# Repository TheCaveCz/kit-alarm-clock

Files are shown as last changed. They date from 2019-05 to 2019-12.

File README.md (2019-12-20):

# Alarm clock / Budík

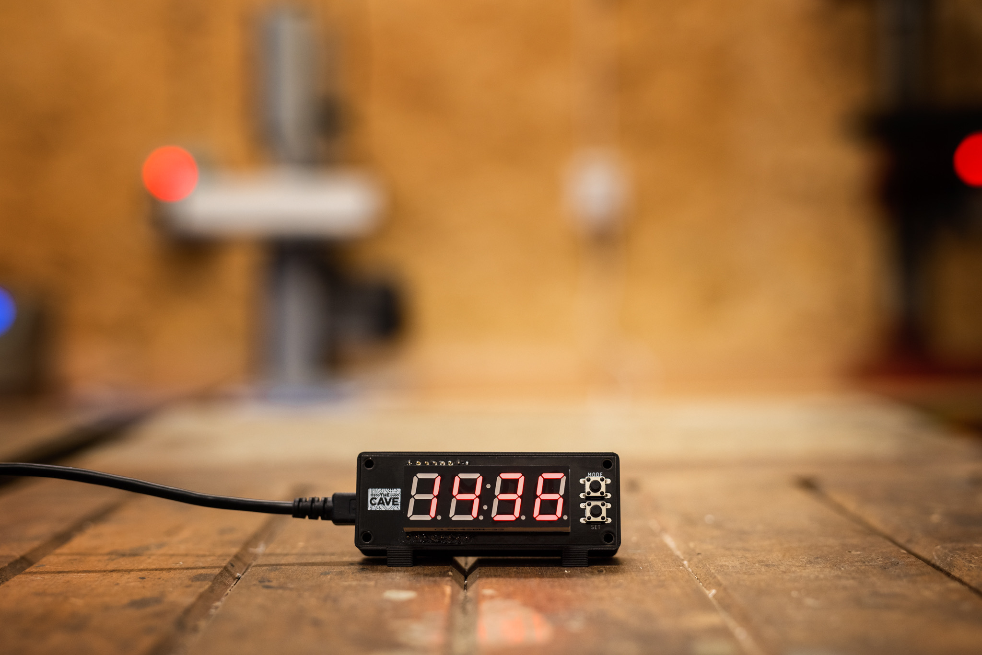
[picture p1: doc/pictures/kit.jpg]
Dice


## Česky

Stavebnice digitálních hodin s budíkem ovládaných přes WiFI.

* [Návod na stavbu](doc/manual-cz.md) ([PDF](doc/manual-cz.pdf))
* [Nastavení budíku a aplikace](doc/blynk-cz.md)
* [Nahrání nového firmware](doc/firmware-cz.md)

## English

Coming soon...

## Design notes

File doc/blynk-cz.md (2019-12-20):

# Nastavení

## Aplikace Blynk

* Stáhněte a nainstalujte si aplikaci Blynk (https://blynk.io/en/getting-started)
* Vytvořte si v aplikaci Blynk nový účet/přihlašte se pokud už účet máte
* Vytvořte v aplikaci nový projekt (New project), device je `Wemos D1 mini`, connection type je `WiFi`
* Blynk odešle na mail zadaný při registraci **Auth token**, ten si zkopírujte nebo opište, budeme jej potřebovat v dalším kroku

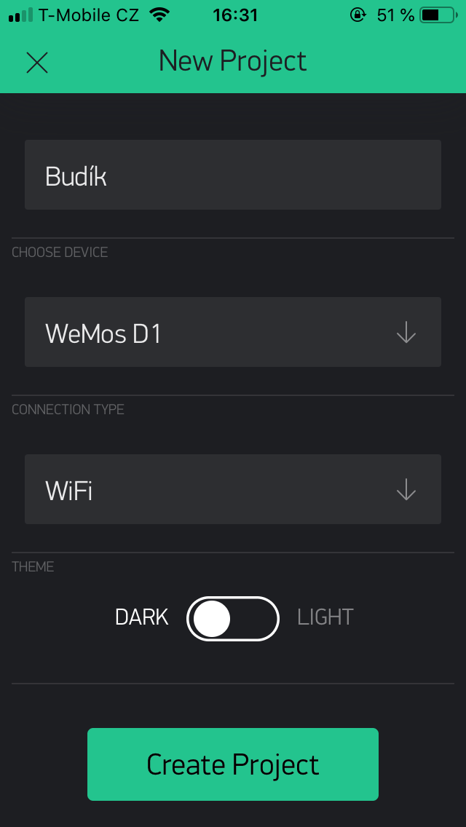
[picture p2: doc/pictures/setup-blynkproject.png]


## Připojení hodin k WiFi

Na displeji hodin musí svítit **AP** a je potřeba mít Blynk **Auth token**. Připojte se na WiFi `alarm-clock-xxxxxx` (xxxxxx je číslo hodin, může se měnit).

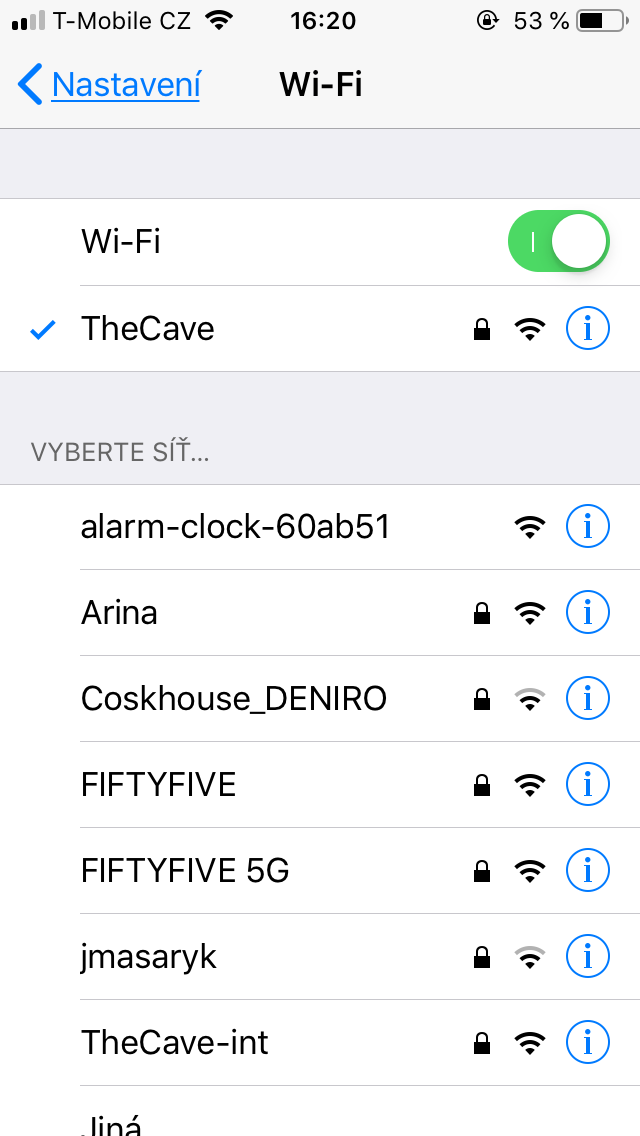
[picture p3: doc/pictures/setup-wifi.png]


Objeví se nastavovací obrazovka (to může chvíli trvat, na některých Android telefonech je potřeba ji ručně otevřít). Pokud se obrazovka neobjeví, zadejte do prohlížeče adresu http://192.168.4.1/, poté zvolte možnost Configure WiFi a počkejte, dokud se neobjeví výběr WiFi sítí.

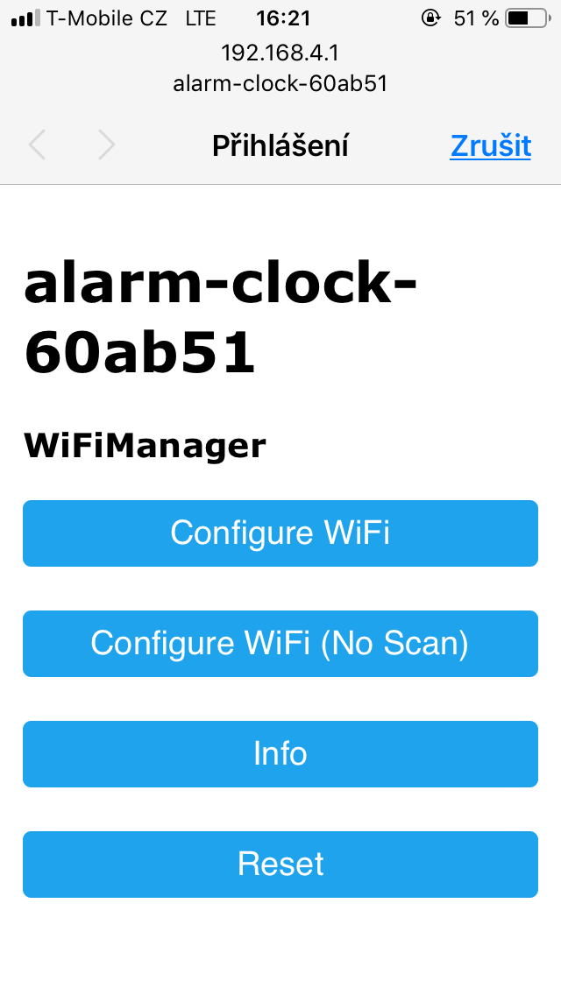
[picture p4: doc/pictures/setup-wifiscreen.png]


Vyberte vaši WiFi síť a do prostředního políčka napište její heslo. Do posledního políčka vložte Auth token a stiskněte tlačítko `Save`

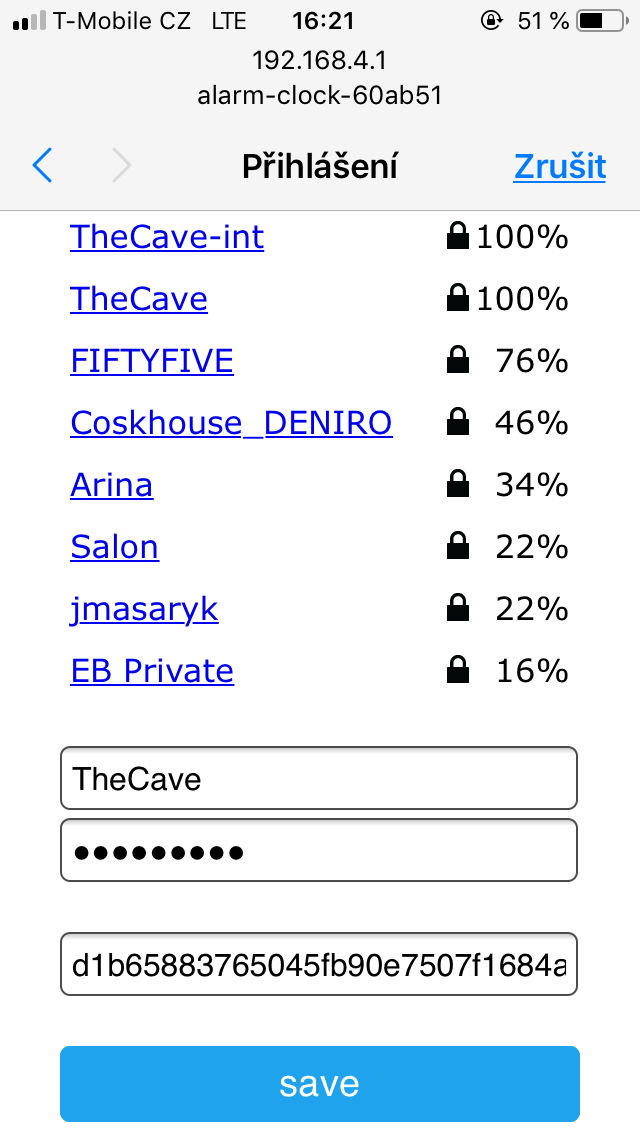
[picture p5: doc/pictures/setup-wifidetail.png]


Po připojení k WiFi na hodinách svítí nuly.

## Nastavení projektu Blynk

Otevřete aplikaci Blynk a zvolte projekt budíku. Obrazovka by měla vypadat podobně.

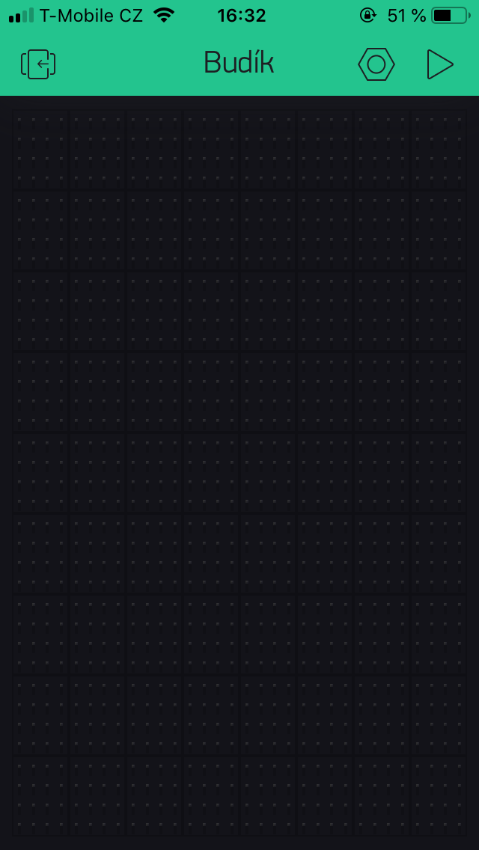
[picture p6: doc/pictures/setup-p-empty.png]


V aplikaci Blynk otevřete projekt a přidejte první kompnentu (na Androidu klepnutím na plus v kolečku, na iOS swipem doleva).

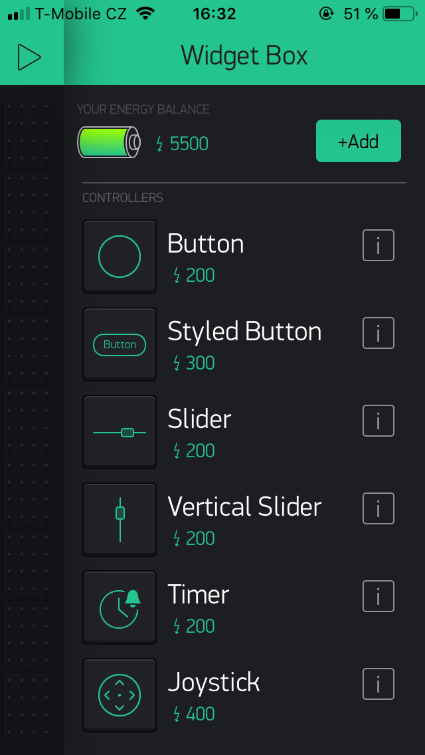
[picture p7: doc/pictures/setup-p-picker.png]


První komponenta, kterou přidáme je **Real-time Clock**. Klepněte na ikonu Play v pravém horním rohu a restartujte hodiny (stiskem tlačítka reset nebo odpojením a připojením kabelu). Pokud vše proběhlo v pořádku, na displeji je aktuální čas.

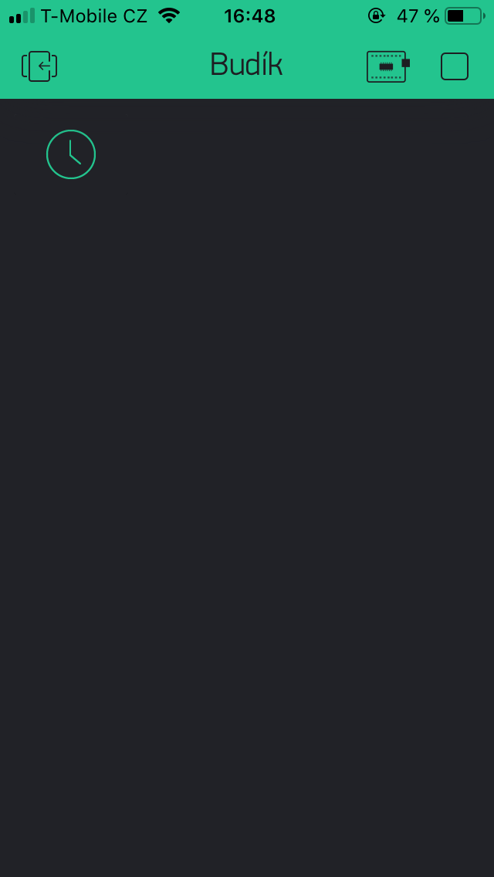
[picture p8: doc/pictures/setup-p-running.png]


Klepněte na ikonu Stop a přidejte další komponenty: **Time Input**, .**Button** a **Notification**. Klepnutím na každou komponentu Time Input otevřete její nastavení a nastavte ji podle následujícího obrázku:

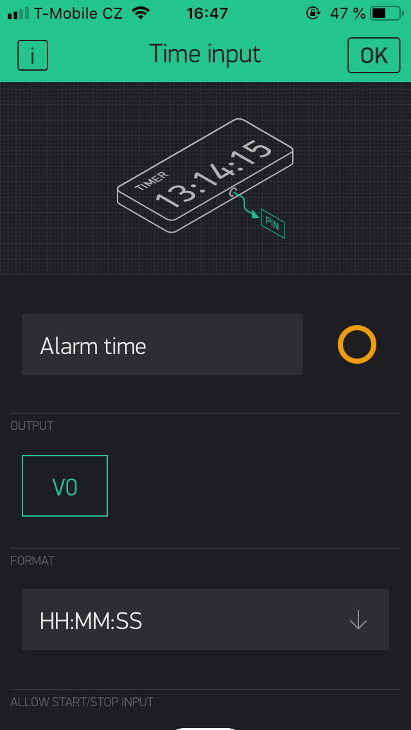
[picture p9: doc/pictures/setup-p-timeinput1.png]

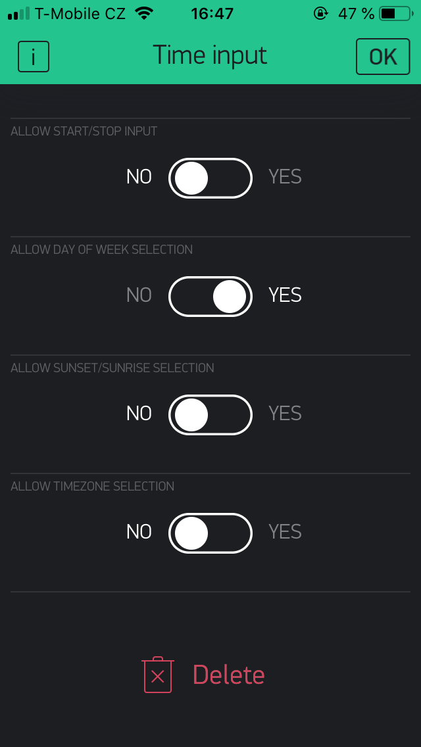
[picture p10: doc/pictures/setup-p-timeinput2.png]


Další komponenta, kterou nastavíme je Button:

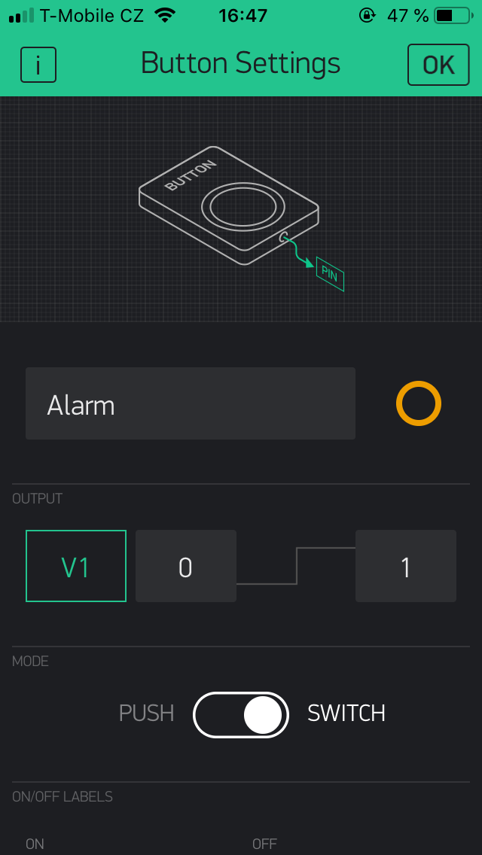
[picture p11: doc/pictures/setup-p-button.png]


Další komponenta je Notification:

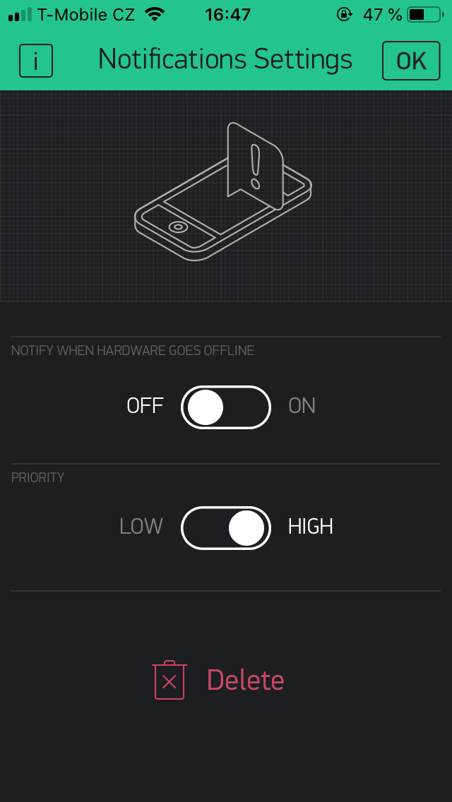
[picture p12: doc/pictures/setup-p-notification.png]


A je to, základní nastavení je hotovo, nyní stiskněte ikonu Play a projekt by měl vypadat nějak takto:

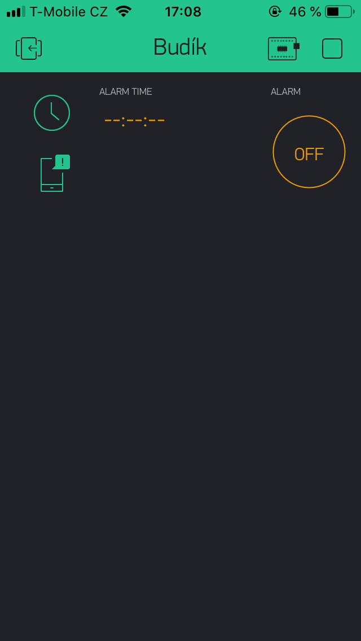
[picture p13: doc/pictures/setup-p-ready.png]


Klepnutím na Alarm time můžete nastavit čas a dny alarmu.

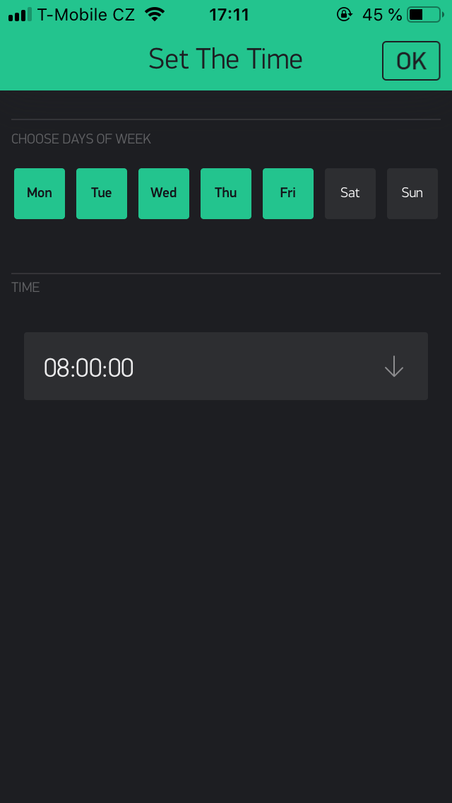
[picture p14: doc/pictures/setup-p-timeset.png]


Tímto jste úspěšně nastavili vše potřebné pro provoz budíku, gratulujeme!

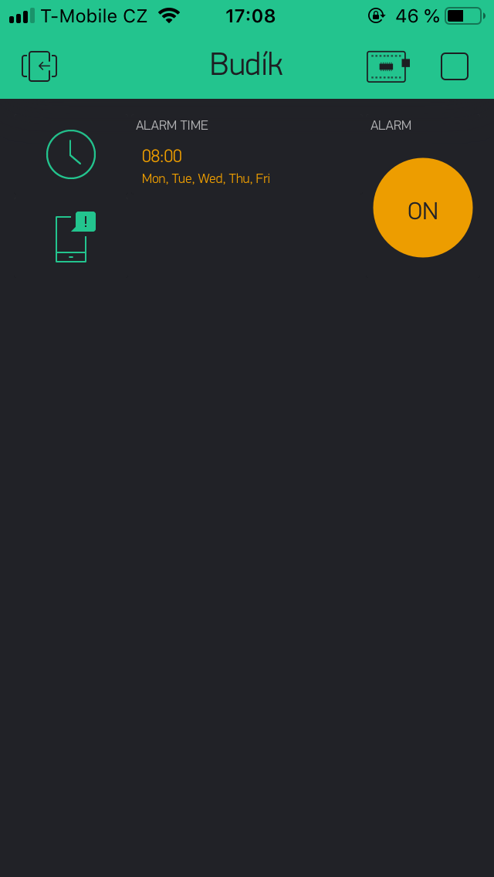
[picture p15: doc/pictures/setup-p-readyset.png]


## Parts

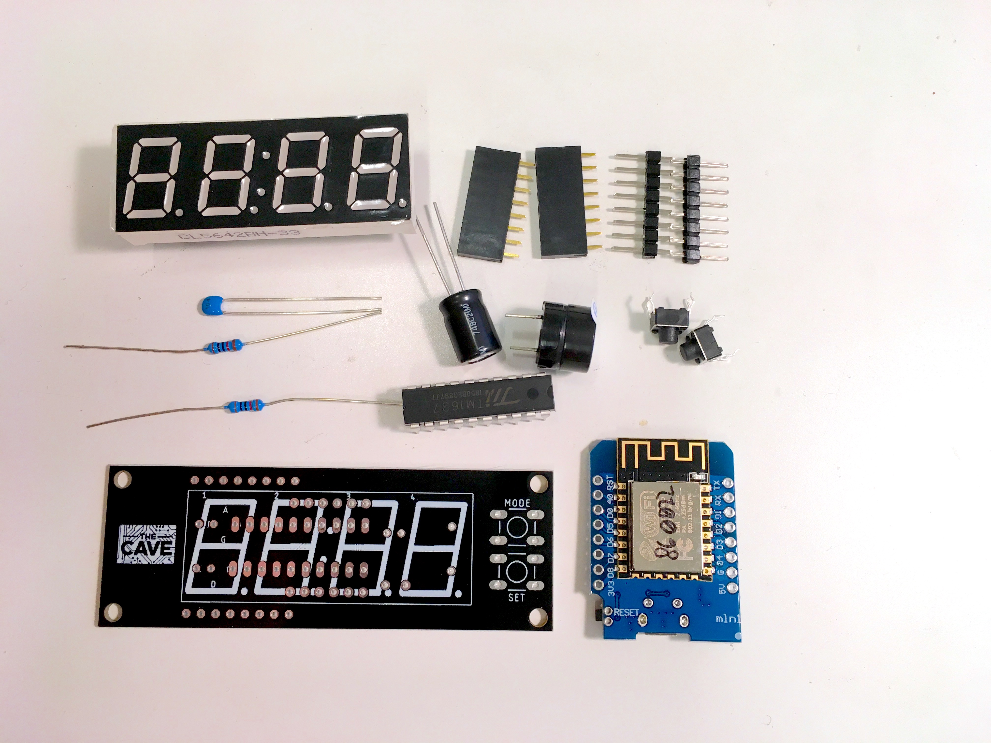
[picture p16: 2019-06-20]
doc/pictures/parts.jpg

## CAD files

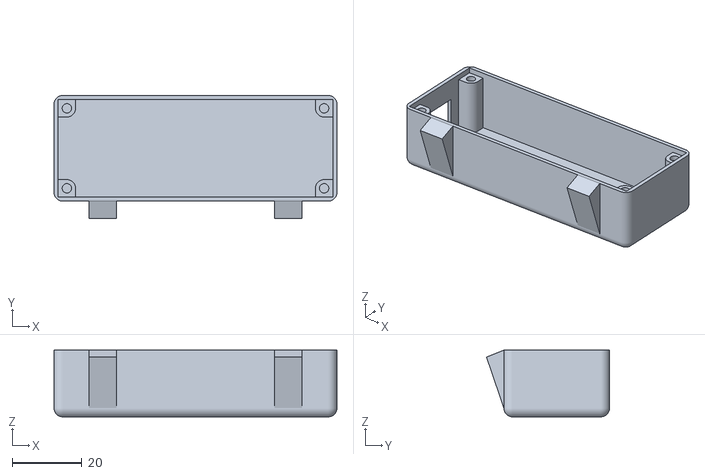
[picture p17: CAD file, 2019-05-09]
stl/box-alarm-clock.stl
81.4 x 35.4 x 19.2

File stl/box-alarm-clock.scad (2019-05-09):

/*
 * Alarm clock kit box
 * 
 * The Cave, 2019
 * https://thecave.cz
 * 
 * Licensed under MIT License (see LICENSE file for details)
 *
 */
$pcbW = 79;
$pcbH = 28;
$pcbThickness = 1.6;
$innerZ = 18;

$usbW = 12;
$usbH = 10;
$usbOffsetZ = 6.5;
$usbOffsetY = 0.5;

$wall = 1.2;
$radius = 5.08;
$fn=100;

$standZ = $innerZ-$pcbThickness;
$standDia = 5;

difference() {
    translate([$radius/2,$radius/2,$radius/2]) minkowski() {
        cube([$pcbW+$wall*2-$radius,$pcbH+$wall*2-$radius,$innerZ+$radius*2+$wall]);
        sphere(d=$radius);
    }
    
    translate([$wall,$wall,$wall]) cube([$pcbW,$pcbH,$innerZ+1]);
    translate([-1,-1,$wall+$innerZ]) cube([$pcbW+$wall*2+10,$pcbH+$wall*2+10,30]);
    
    translate([-1, (($wall*2+$pcbH-$usbW)/2)-$usbOffsetY, $wall+$innerZ-$usbOffsetZ-$usbH]) #cube([$wall*4,$usbW,$usbH]);
}

translate([$wall,$wall,$wall]) {
    difference() {
        union() {
            translate([$standDia/2,$standDia/2,0]) cylinder(d=$standDia,h=$standZ);
            cube([$standDia,$standDia/2,$standZ]);
            cube([$standDia/2,$standDia,$standZ]);
            
            translate([$pcbW-$standDia/2,$standDia/2,0]) cylinder(d=$standDia,h=$standZ);
            translate([$pcbW-$standDia,0,0]) cube([$standDia,$standDia/2,$standZ]);
            translate([$pcbW-$standDia/2,0,0]) cube([$standDia/2,$standDia,$standZ]);
            
            translate([$standDia/2,$pcbH-$standDia/2,0]) cylinder(d=$standDia,h=$standZ);
            translate([0,$pcbH-$standDia/2,0]) cube([$standDia,$standDia/2,$standZ]);
            translate([0,$pcbH-$standDia,0]) cube([$standDia/2,$standDia,$standZ]);
            
            translate([$pcbW-$standDia/2,$pcbH-$standDia/2,0]) cylinder(d=$standDia,h=$standZ);
            translate([$pcbW-$standDia,$pcbH-$standDia/2,0]) cube([$standDia,$standDia/2,$standZ]);
            translate([$pcbW-$standDia/2,$pcbH-$standDia,0]) cube([$standDia/2,$standDia,$standZ]);
        }
        
        translate([$standDia/2,$standDia/2,0]) #cylinder(d=2.7,h=$standZ+5);
        translate([$pcbW-$standDia/2,$standDia/2,0]) #cylinder(d=2.7,h=$standZ+5);
        translate([$standDia/2,$pcbH-$standDia/2,0]) #cylinder(d=2.7,h=$standZ+5);
        translate([$pcbW-$standDia/2,$pcbH-$standDia/2,0]) #cylinder(d=2.7,h=$standZ+5);
    }
}

$legOffset = -5;
$legWidth = 8;
module leg() { polyhedron(
    points=[[0,0,$radius/2],[0,0,$wall+$innerZ],[0,$legOffset,$wall+$innerZ-2],[$legWidth,0,$radius/2],[$legWidth,0,$wall+$innerZ],[$legWidth,$legOffset,$wall+$innerZ-2]],
    faces=[[0,1,2],[2,1,4,5],[5,4,3],[3,4,1,0],[3,0,2,5]],
    convexity=1
);
}

translate([10,0,0]) leg();
translate([$wall*2+$pcbW-$legWidth-10,0,0]) leg();

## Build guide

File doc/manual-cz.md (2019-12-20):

# Návod na stavbu

[Stáhnout PDF](manual-cz.pdf)

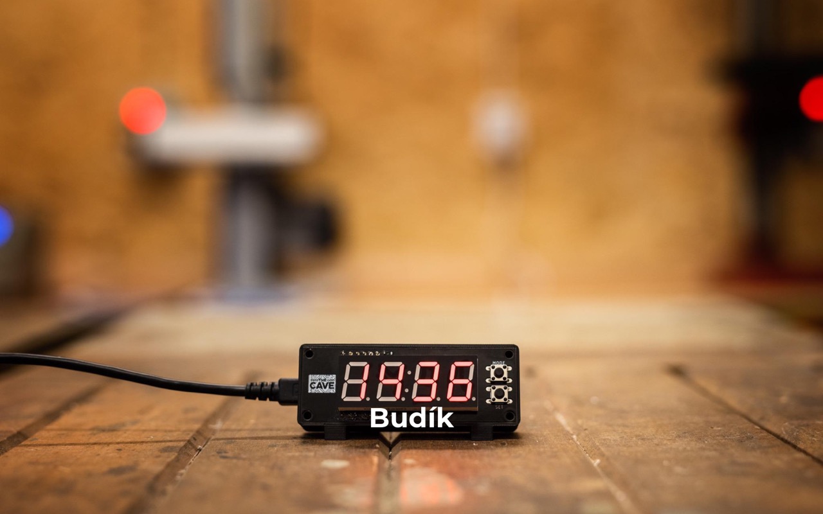
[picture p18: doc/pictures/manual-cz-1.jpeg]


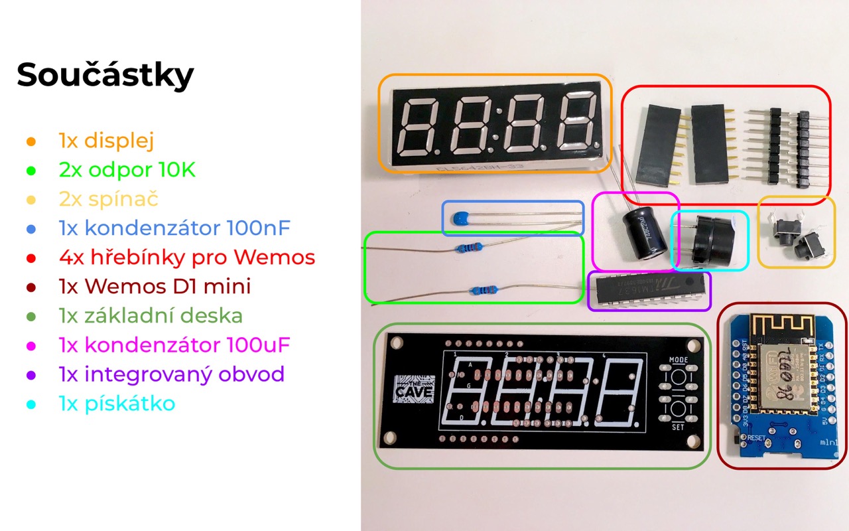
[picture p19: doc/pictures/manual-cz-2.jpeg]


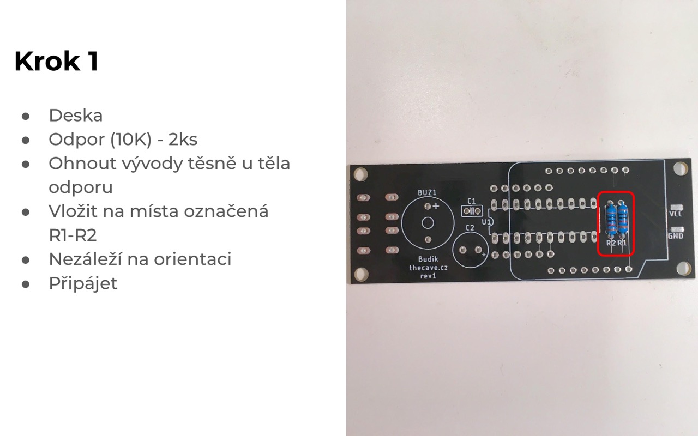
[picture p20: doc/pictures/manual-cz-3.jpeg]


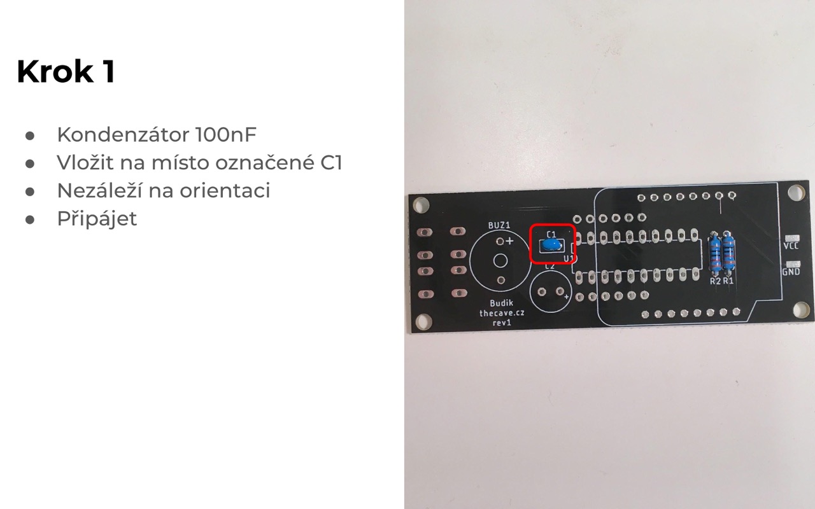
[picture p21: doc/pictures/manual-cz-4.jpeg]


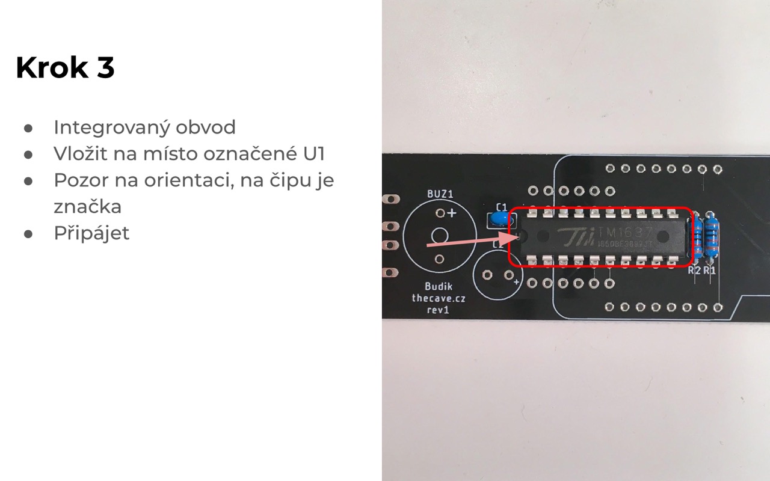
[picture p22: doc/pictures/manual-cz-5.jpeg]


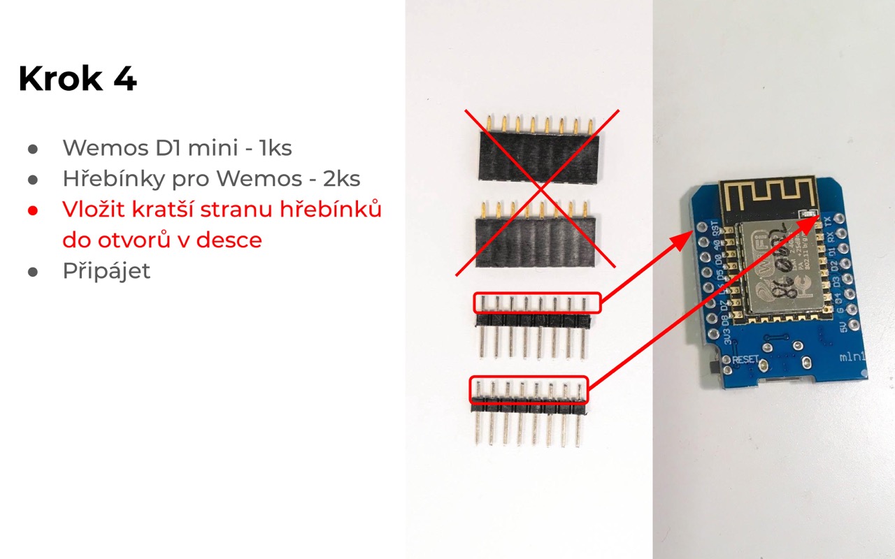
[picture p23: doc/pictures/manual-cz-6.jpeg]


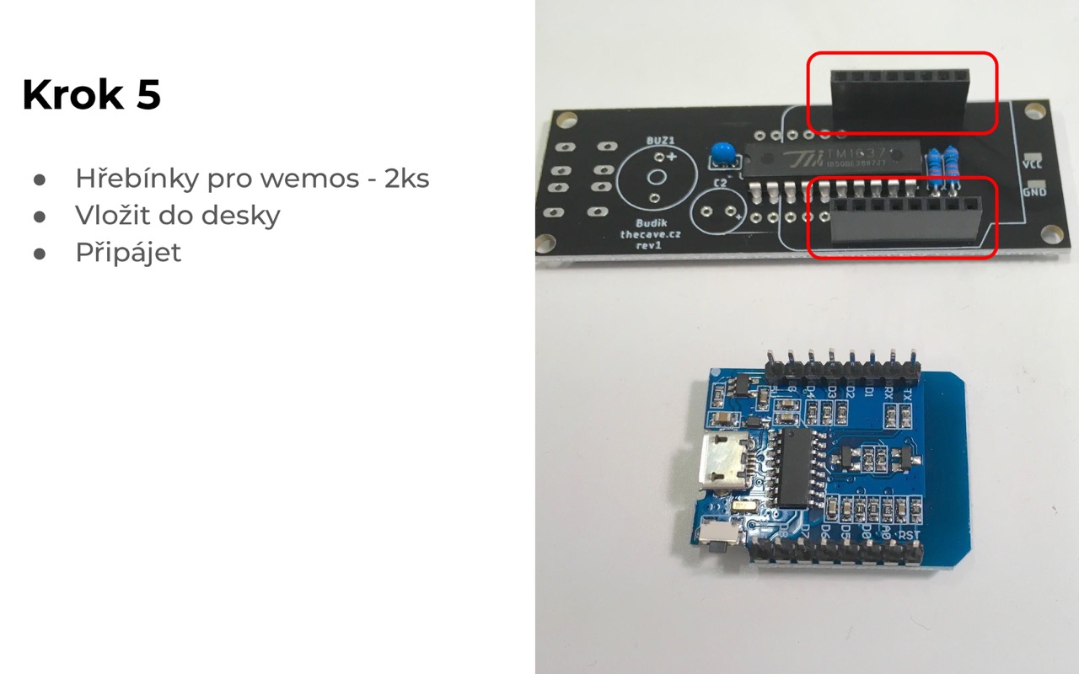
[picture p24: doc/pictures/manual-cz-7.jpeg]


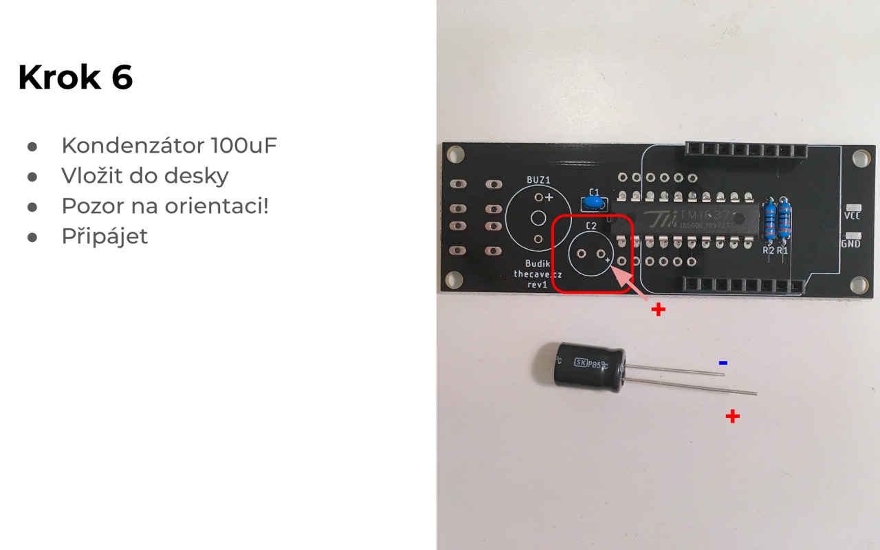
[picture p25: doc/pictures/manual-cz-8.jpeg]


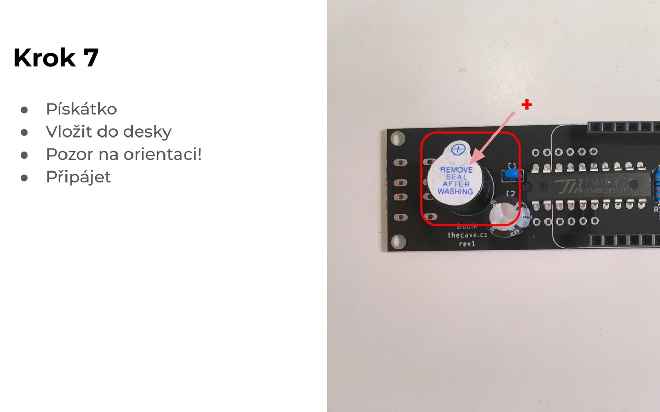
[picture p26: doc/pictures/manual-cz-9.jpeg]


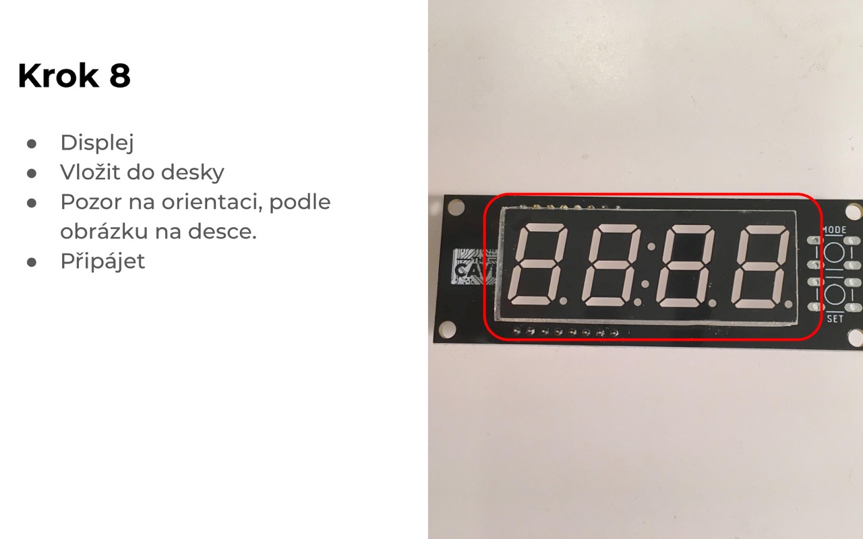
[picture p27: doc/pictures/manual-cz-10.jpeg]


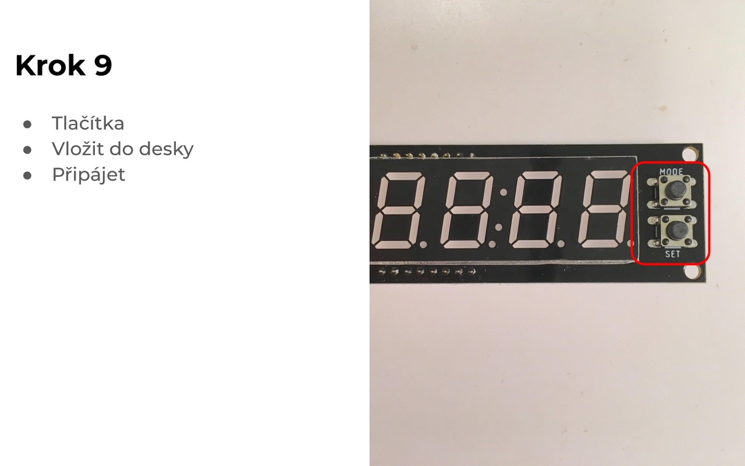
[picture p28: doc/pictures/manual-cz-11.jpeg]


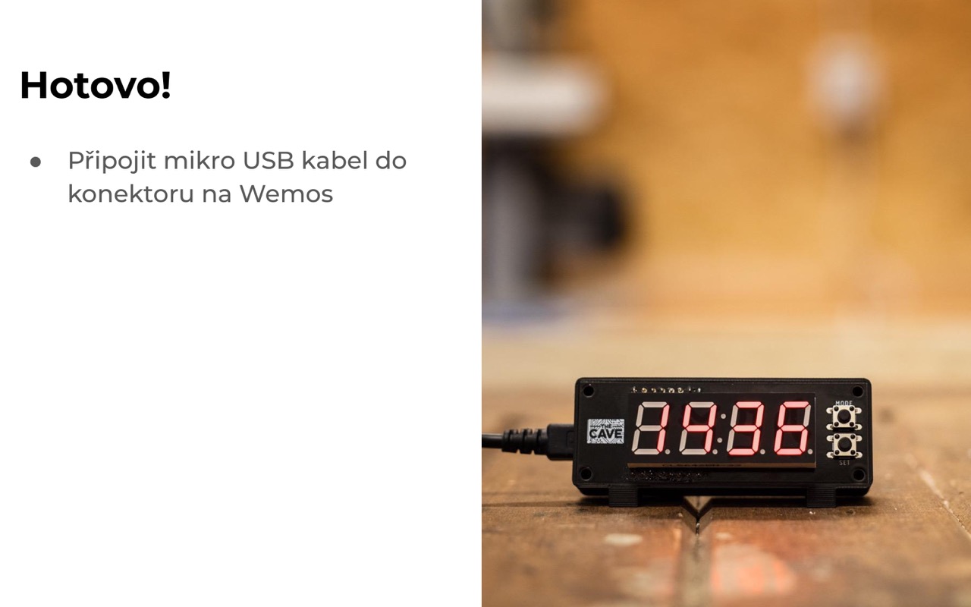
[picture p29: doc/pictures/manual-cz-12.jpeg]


[Nastavení budíku a aplikace](blynk-cz.md)

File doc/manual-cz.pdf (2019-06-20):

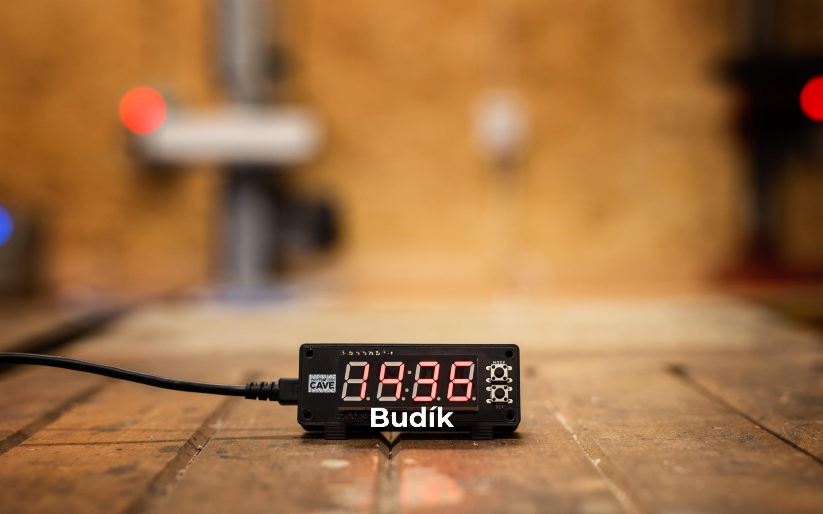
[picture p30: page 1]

## Budík

## Součástky

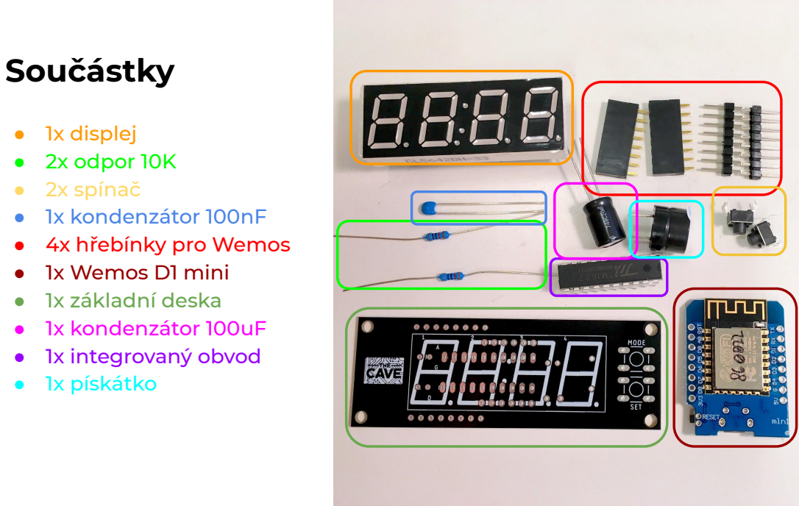
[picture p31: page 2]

● 1x displej
● 2x odpor 10K
● 2x spínač
● 1x kondenzátor 100nF
● 4x hřebínky pro Wemos
● 1x Wemos D1 mini
● 1x základní deska
● 1x kondenzátor 100uF
● 1x integrovaný obvod
● 1x pískátko

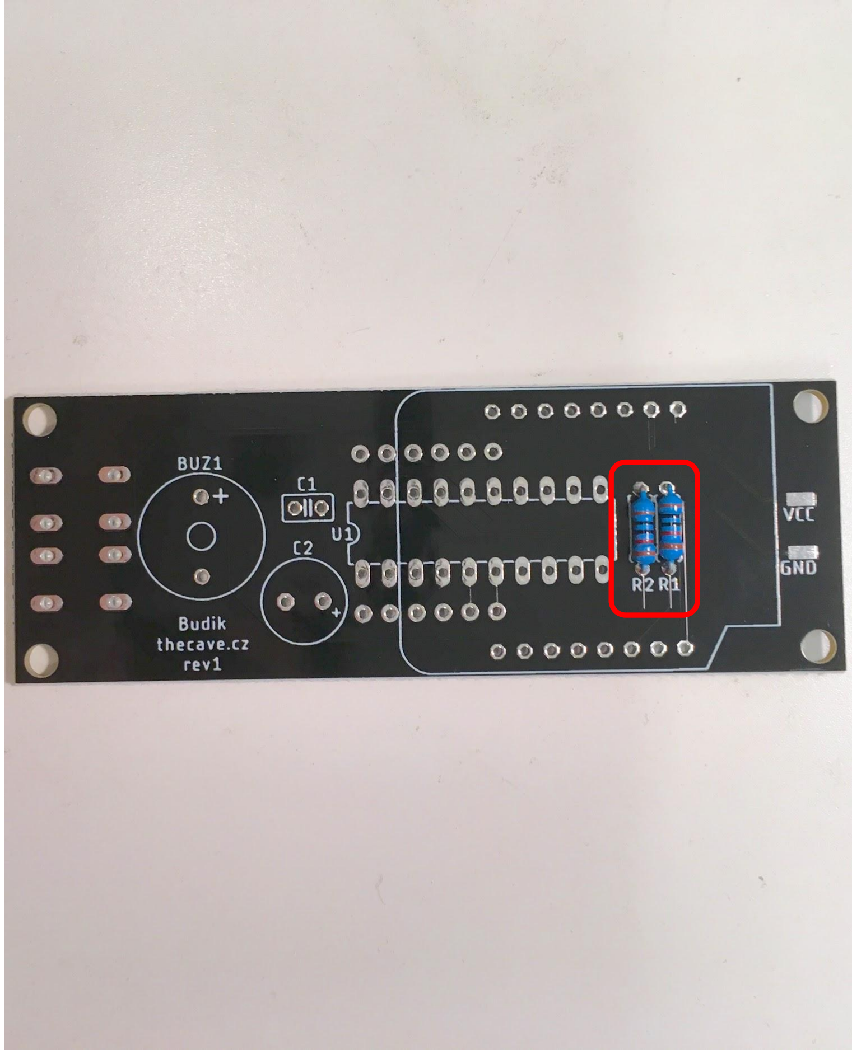
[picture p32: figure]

## Krok 1

- Deska
- Odpor (10K) - 2ks
- Ohnout vývody těsně u těla odporu
- Vložit na místa označená R1-R2
- Nezáleží na orientaci
- Připájet

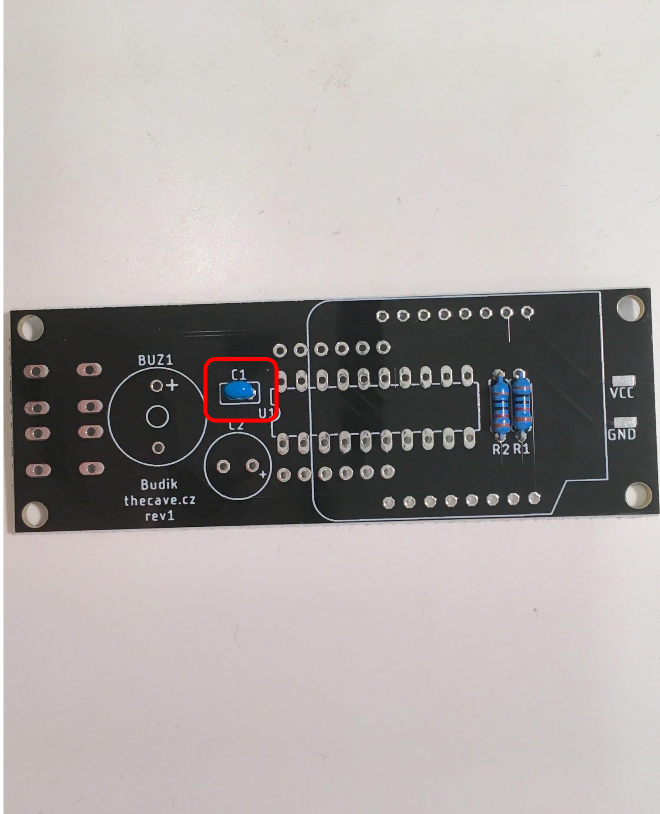
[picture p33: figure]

## Krok 1

- Kondenzátor 100nF
- Vložit na místo označené C1
- Nezáleží na orientaci
- Připájet

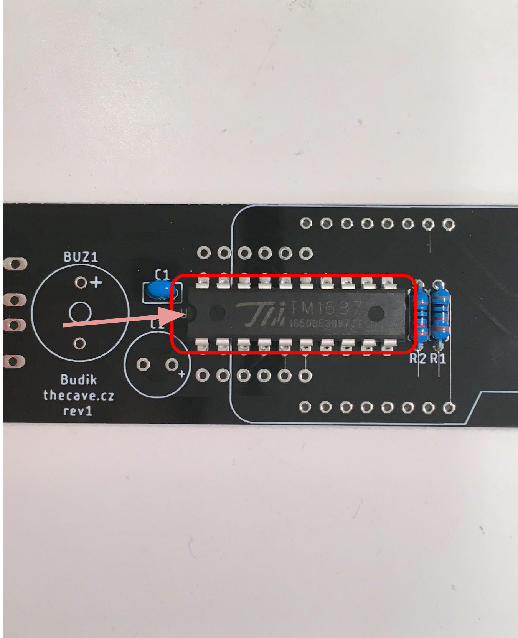
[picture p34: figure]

## Krok 3

- Integrovaný obvod
- Vložit na místo označené U1
- Pozor na orientaci, na čipu je značka
- Připájet

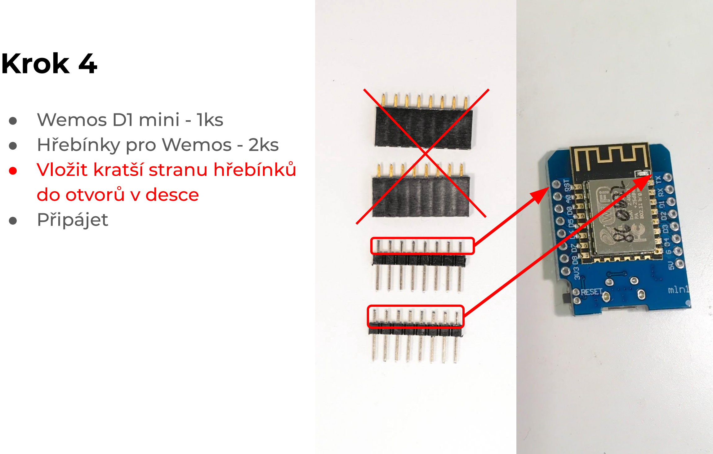
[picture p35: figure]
Krok 4; ● Wemos D1 mini - 1ks ● Hřebínky pro Wemos - 2ks ● Vložit kratší stranu hřebínků do otvorů v desce ● Připájet

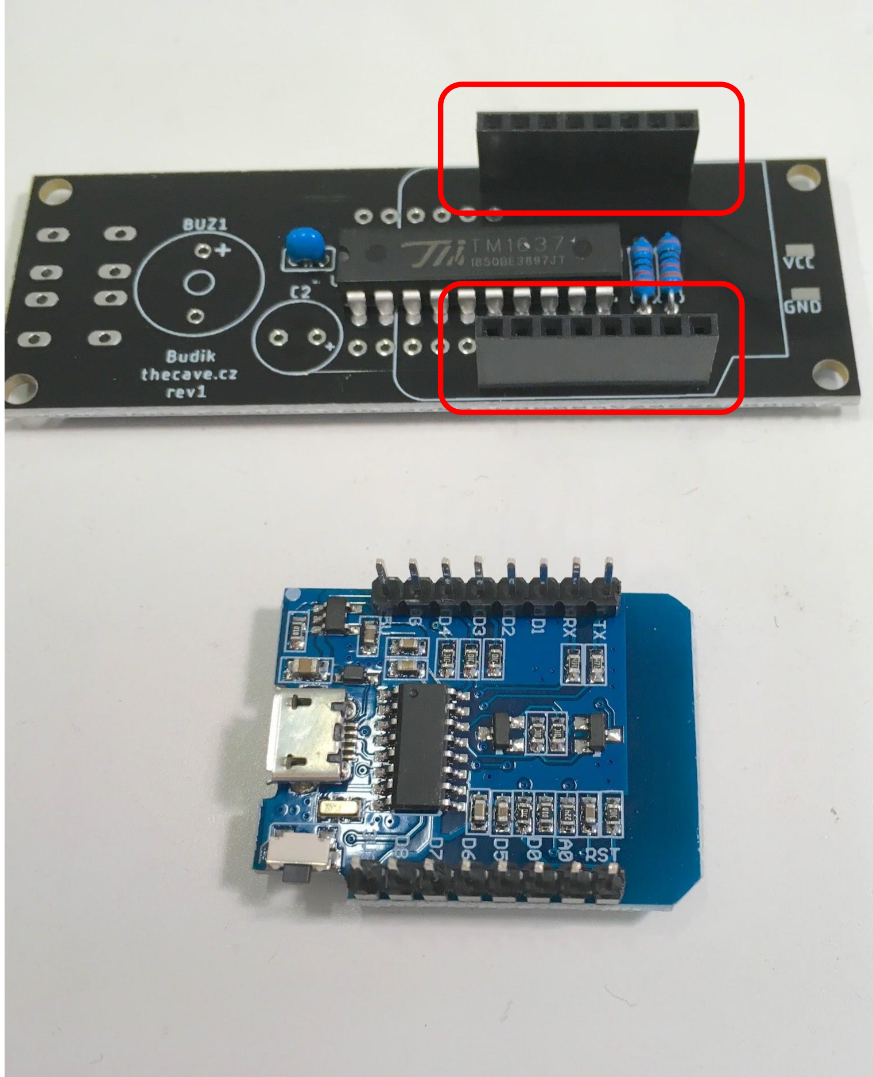
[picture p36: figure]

## Krok 5

- Hřebínky pro wemos - 2ks
- Vložit do desky
- Připájet

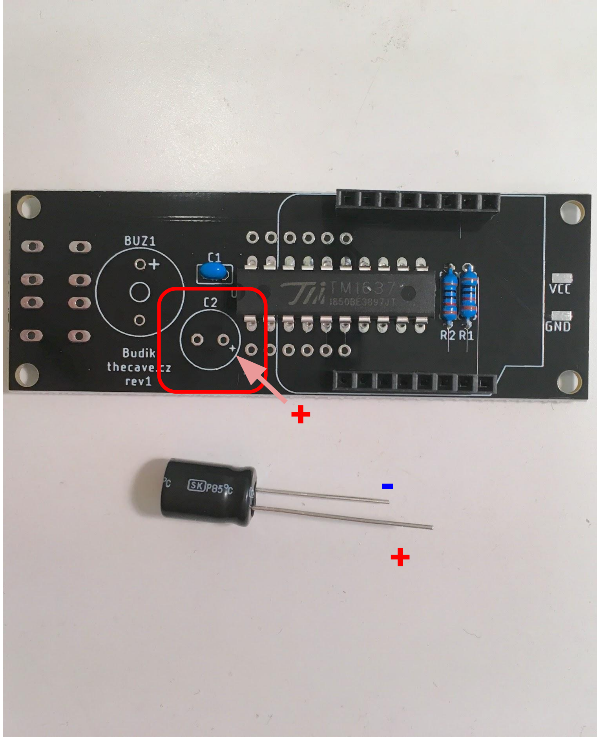
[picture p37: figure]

## Krok 6

- Kondenzátor 100uF
- Vložit do desky
- Pozor na orientaci!
- Připájet

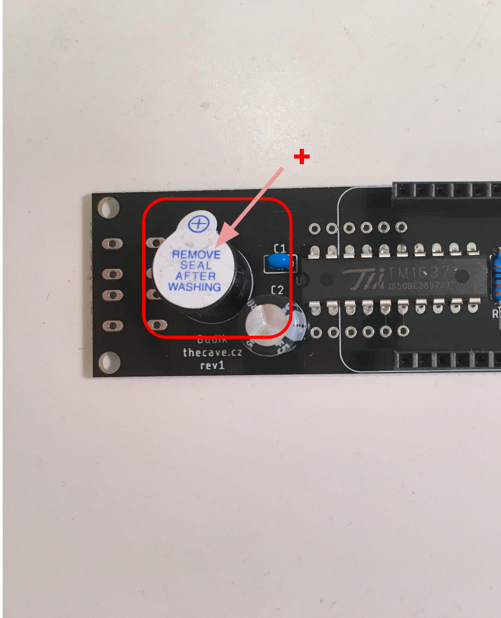
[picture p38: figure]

Krok 7 ● Pískátko ● Vložit do desky ● Pozor na orientaci! ● Připájet

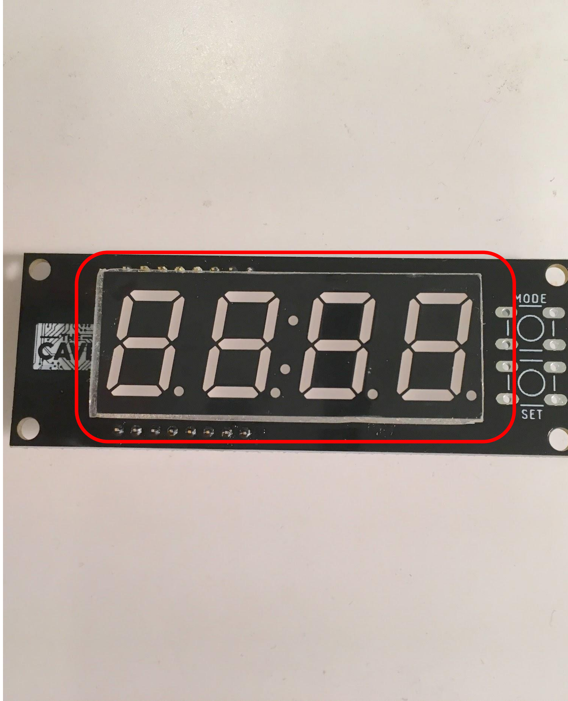
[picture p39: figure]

## Krok 8

- Displej
- Vložit do desky
- Pozor na orientaci, podle obrázku na desce.
- Připájet

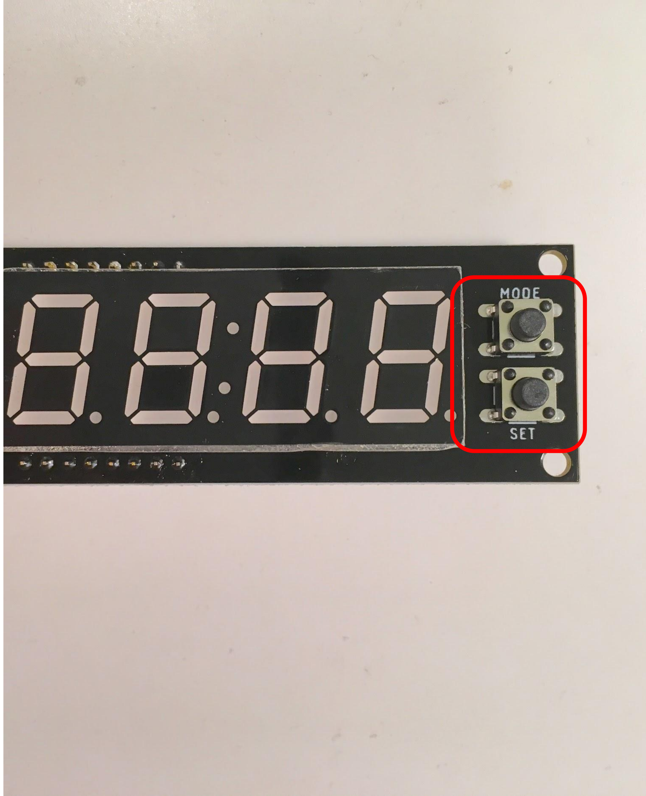
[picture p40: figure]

## Krok 9

- Tlačítka
- Vložit do desky
- Připájet

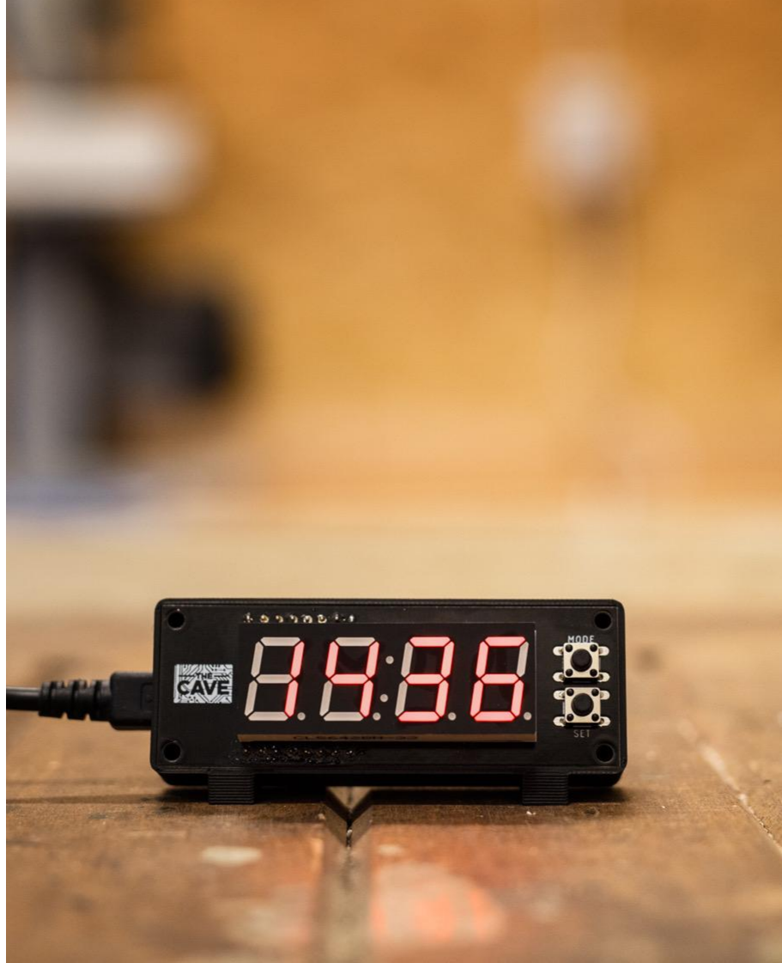
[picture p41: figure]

## Hotovo!

- Připojit mikro USB kabel do konektoru na Wemos

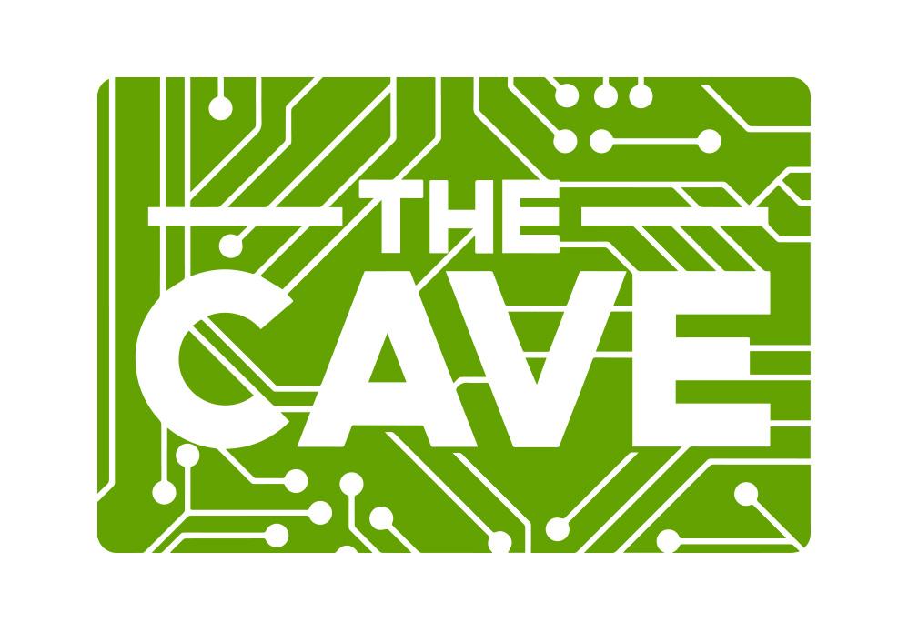
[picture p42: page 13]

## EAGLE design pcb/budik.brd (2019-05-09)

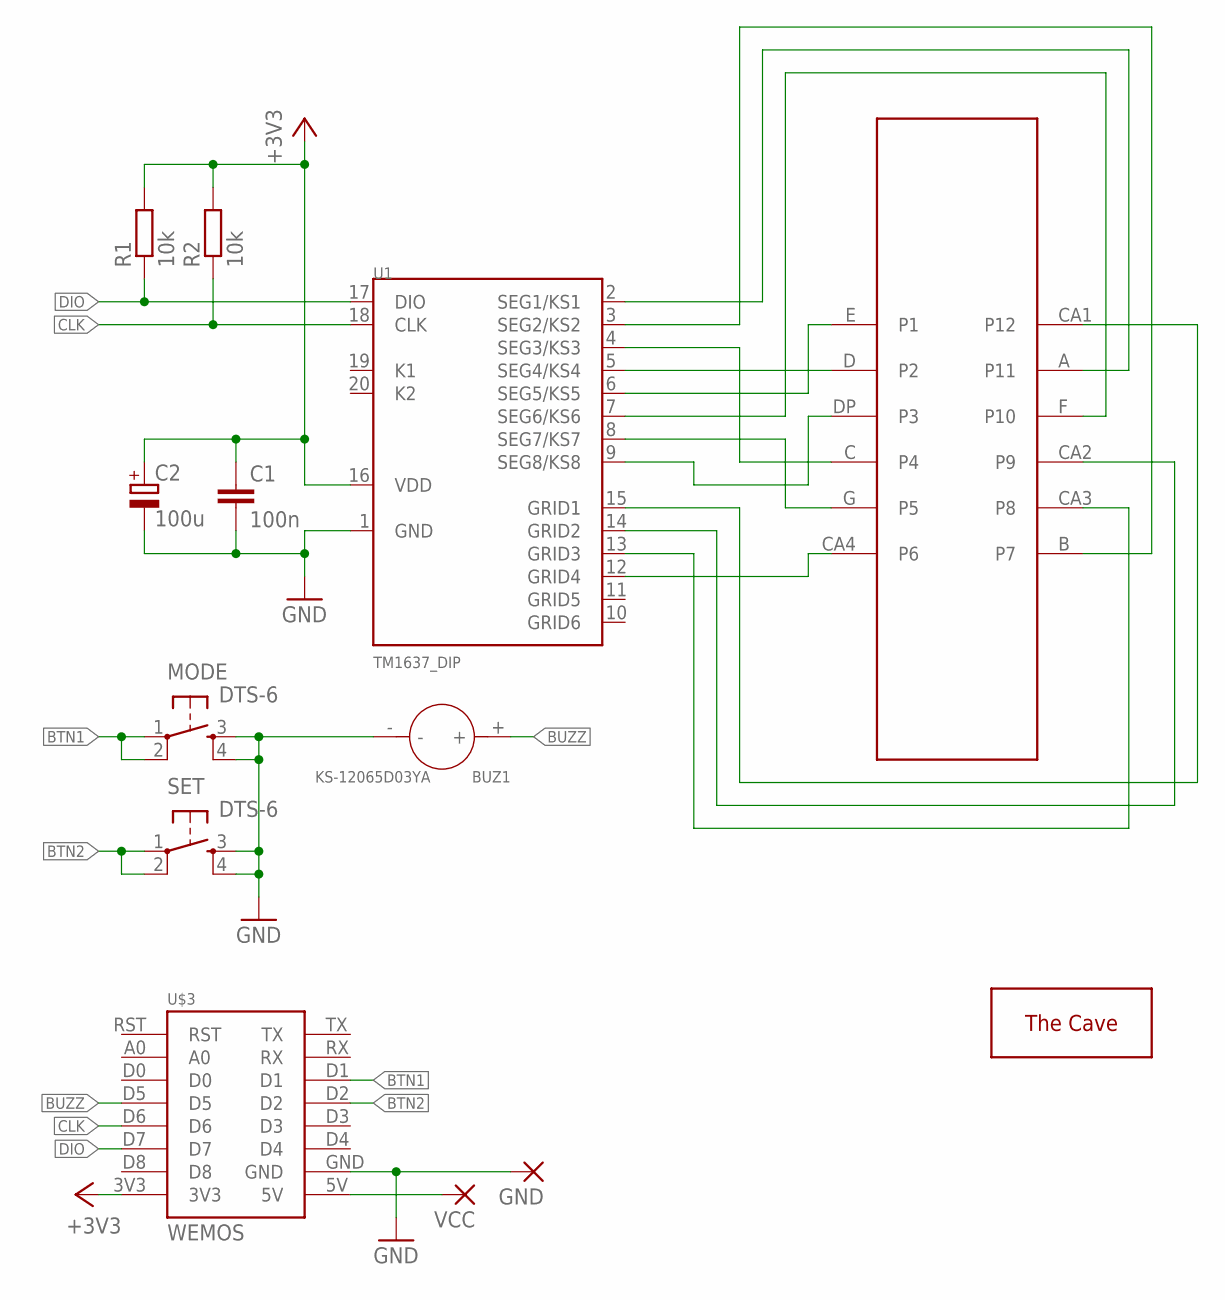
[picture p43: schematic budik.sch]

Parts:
BUZ1: KS-12065D03YA; BZ2-7.6-D12.0XH6.5MM
C1: 100n; C025-025X050
C2: 100u; E3,5-8
GND: WIREPADSMD1,27-254; SMD1,27-2,54
MODE: DTS-6
R1, R2: 10k; 0207/7
SET: DTS-6
U1: TM1637_DIP; DIL20
U$1: NFD-5642BX; DISPLAY
U$2: THECAVE_LOGO_NEW_TOP_SMALL; NEW_LOGO_SMALL_TOP
U$3: WEMOS
VCC: WIREPADSMD1,27-254; SMD1,27-2,54

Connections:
+3V3: C1.1, C2.+, R1.2, R2.2, U1.16 (VDD), U$3.3V3
BTN1: MODE.1, MODE.2, U$3.D1
BTN2: SET.1, SET.2, U$3.D2
BUZZ: BUZ1.+, U$3.D5
CLK: R2.1, U1.18 (CLK), U$3.D6
DIO: R1.1, U1.17 (DIO), U$3.D7
GND: BUZ1.-, C1.2, C2.-, GND.1, MODE.3, MODE.4, SET.3, SET.4, U1.1 (GND), U$3.GND
unnamed: U$3.5V, VCC.1
unnamed: U1.2 (SEG1/KS1), U$1.A (P11)
unnamed: U1.3 (SEG2/KS2), U$1.B (P7)
unnamed: U1.4 (SEG3/KS3), U$1.C (P4)
unnamed: U1.5 (SEG4/KS4), U$1.D (P2)
unnamed: U1.6 (SEG5/KS5), U$1.E (P1)
unnamed: U1.7 (SEG6/KS6), U$1.F (P10)
unnamed: U1.8 (SEG7/KS7), U$1.G (P5)
unnamed: U1.9 (SEG8/KS8), U$1.DP (P3)
unnamed: U1.15 (GRID1), U$1.CA1 (P12)
unnamed: U1.14 (GRID2), U$1.CA2 (P9)
unnamed: U1.13 (GRID3), U$1.CA3 (P8)
unnamed: U1.12 (GRID4), U$1.CA4 (P6)

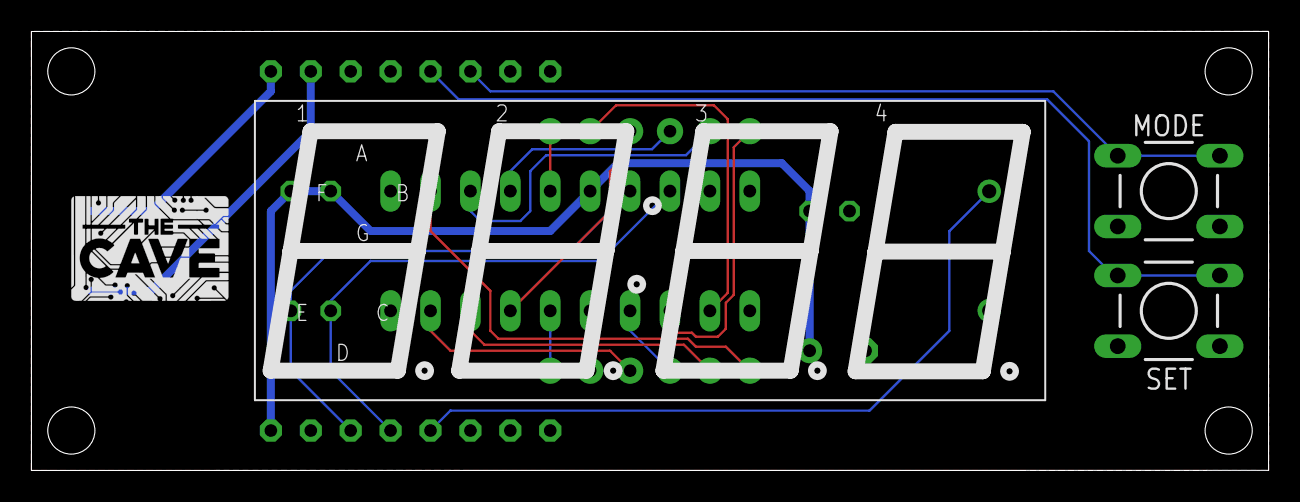
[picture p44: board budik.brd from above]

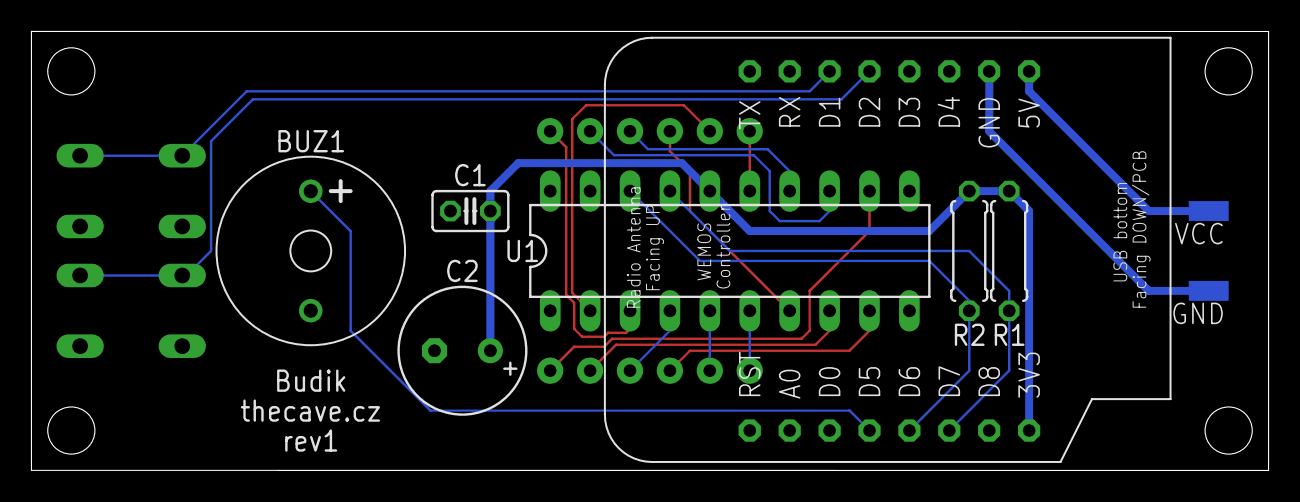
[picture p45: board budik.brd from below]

Board: 2 copper layers, 78.7 x 27.9 mm, 13 parts (9 on the bottom side), 20 nets.

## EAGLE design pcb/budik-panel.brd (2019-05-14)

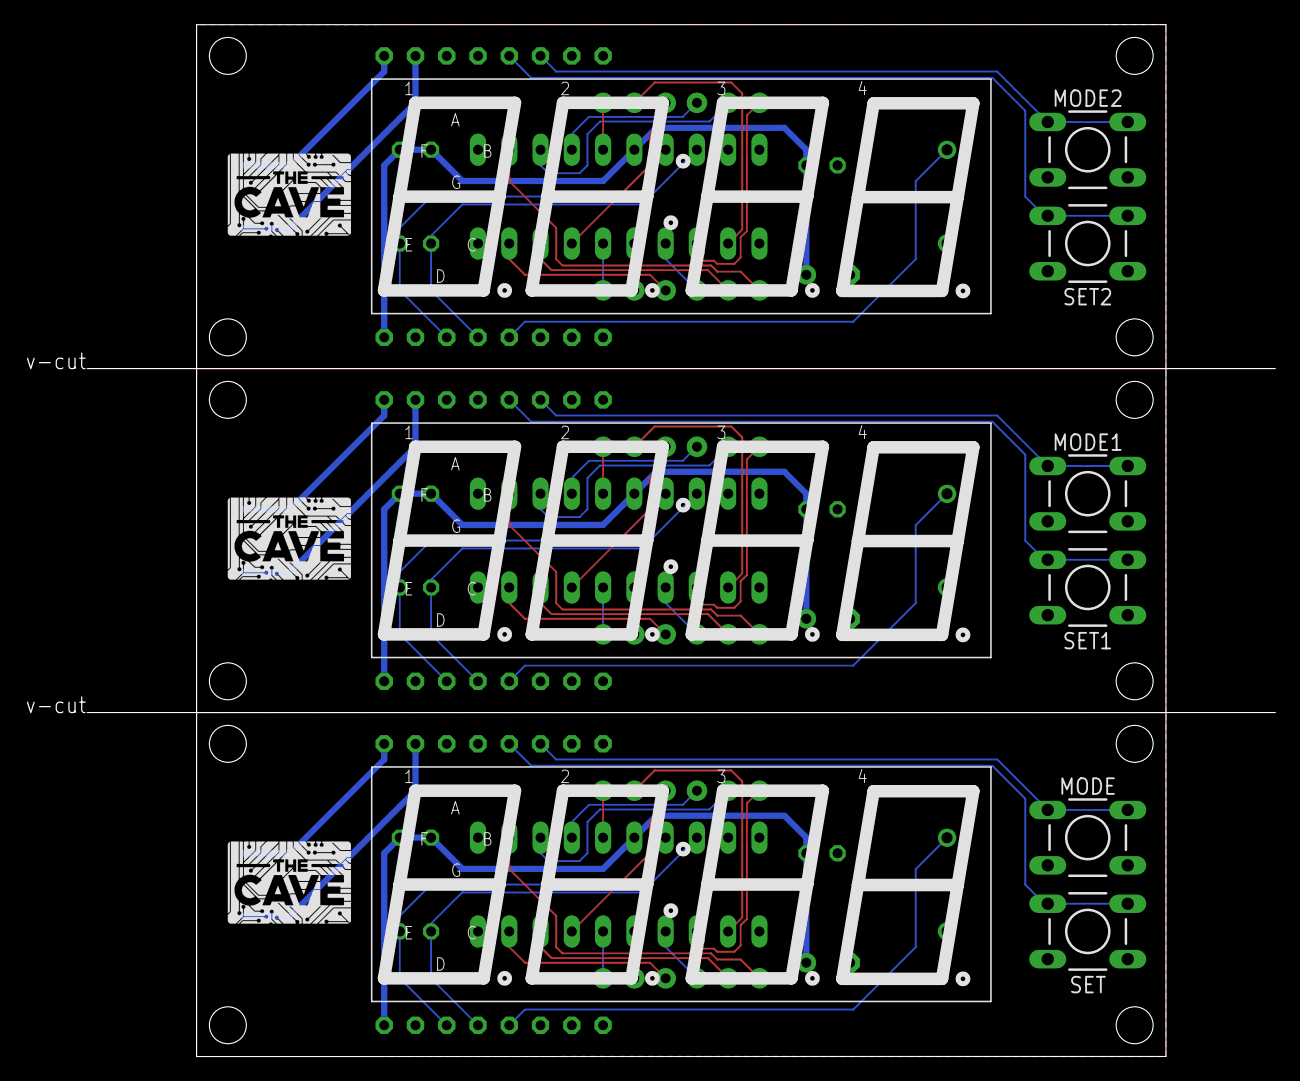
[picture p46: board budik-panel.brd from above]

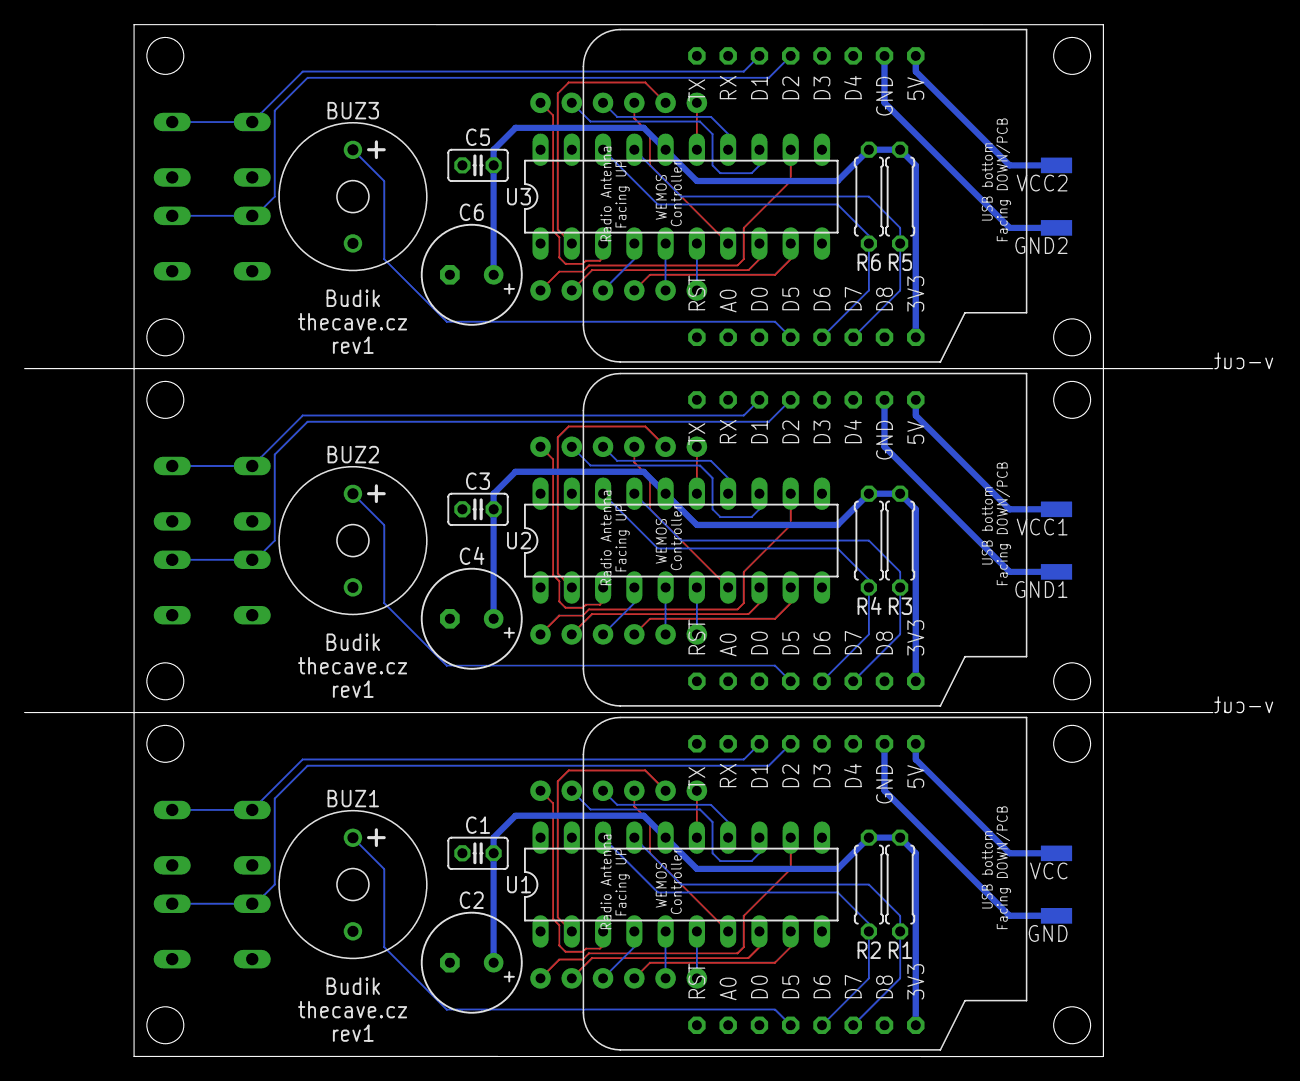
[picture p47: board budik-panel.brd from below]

Board: 2 copper layers, 78.7 x 83.8 mm, 39 parts (27 on the bottom side), 60 nets.

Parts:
BUZ1, BUZ2, BUZ3: KS-12065D03YA; BZ2-7.6-D12.0XH6.5MM
C1, C3, C5: 100n; C025-025X050
C2, C4, C6: 100u; E3,5-8
GND, GND1, GND2: SMD1,27-2,54
MODE, MODE1, MODE2: DTS-6
R1, R2, R3, R4, R5, R6: 10k; 0207/7
SET, SET1, SET2: DTS-6
U1, U2, U3: TM1637_DIP; DIL20
U$1, U$4, U$7: NFD-5642BX; DISPLAY
U$2, U$5, U$8: THECAVE_LOGO_NEW_TOP_SMALL; NEW_LOGO_SMALL_TOP
U$3, U$6, U$9: WEMOS
VCC, VCC1, VCC2: SMD1,27-2,54

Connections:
+3V1: C3.1, C4.+, R3.2, R4.2, U2.16, U$6.3V3
+3V2: C5.1, C6.+, R5.2, R6.2, U3.16, U$9.3V3
+3V3: C1.1, C2.+, R1.2, R2.2, U1.16, U$3.3V3
BTN1: MODE.1, MODE.2, U$3.D1
BTN2: SET.1, SET.2, U$3.D2
BTN3: MODE1.1, MODE1.2, U$6.D1
BTN4: SET1.1, SET1.2, U$6.D2
BTN5: MODE2.1, MODE2.2, U$9.D1
BTN6: SET2.1, SET2.2, U$9.D2
BUZZ: BUZ1.+, U$3.D5
BUZZ1: BUZ2.+, U$6.D5
BUZZ2: BUZ3.+, U$9.D5
CLK: R2.1, U1.18, U$3.D6
CLK1: R4.1, U2.18, U$6.D6
CLK2: R6.1, U3.18, U$9.D6
DIO: R1.1, U1.17, U$3.D7
DIO1: R3.1, U2.17, U$6.D7
DIO2: R5.1, U3.17, U$9.D7
GND: BUZ1.-, C1.2, C2.-, GND.1, MODE.3, MODE.4, SET.3, SET.4, U1.1, U$3.GND
GND1: BUZ2.-, C3.2, C4.-, GND1.1, MODE1.3, MODE1.4, SET1.3, SET1.4, U2.1, U$6.GND
GND2: BUZ3.-, C5.2, C6.-, GND2.1, MODE2.3, MODE2.4, SET2.3, SET2.4, U3.1, U$9.GND
unnamed: U$3.5V, VCC.1
unnamed: U1.2, U$1.A
unnamed: U1.3, U$1.B
unnamed: U1.4, U$1.C
unnamed: U1.5, U$1.D
unnamed: U1.6, U$1.E
unnamed: U1.7, U$1.F
unnamed: U1.8, U$1.G
unnamed: U1.9, U$1.DP
unnamed: U1.15, U$1.CA1
unnamed: U1.14, U$1.CA2
unnamed: U1.13, U$1.CA3
unnamed: U1.12, U$1.CA4
unnamed: U2.2, U$4.A
unnamed: U2.3, U$4.B
unnamed: U2.4, U$4.C
unnamed: U2.5, U$4.D
unnamed: U2.6, U$4.E
unnamed: U2.7, U$4.F
unnamed: U2.8, U$4.G
unnamed: U2.9, U$4.DP
unnamed: U2.15, U$4.CA1
unnamed: U2.14, U$4.CA2
unnamed: U2.13, U$4.CA3
unnamed: U2.12, U$4.CA4
unnamed: U$6.5V, VCC1.1
unnamed: U3.2, U$7.A
unnamed: U3.3, U$7.B
unnamed: U3.4, U$7.C
unnamed: U3.5, U$7.D
unnamed: U3.6, U$7.E
unnamed: U3.7, U$7.F
unnamed: U3.8, U$7.G
unnamed: U3.9, U$7.DP
unnamed: U3.15, U$7.CA1
unnamed: U3.14, U$7.CA2
unnamed: U3.13, U$7.CA3
unnamed: U3.12, U$7.CA4
unnamed: U$9.5V, VCC2.1

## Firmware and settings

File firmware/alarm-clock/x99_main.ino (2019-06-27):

void otaSetup() {
  String hn = WIFI_AP_NAME;
  hn += chipId;
  ArduinoOTA.setHostname(hn.c_str());
  ArduinoOTA.onStart([]() {
    dispShowStatic(DISP_OTA);
    logInfo("OTA starting");
  });
  ArduinoOTA.onEnd([]() {
    logInfo("OTA finished");
  });
  ArduinoOTA.begin();
}

void setup() {
  Serial.begin(115200);
  logInfo("\n\nStarting");
  logValue("chipId: ", chipId);

  beepSetup();
  dispSetup();
  configSetup();
  otaSetup(); // so we can OTA when config portal is up
  logicSetup();
  wifiSetup(); // will block on config portal if not configured
  blynkSetup();

  logInfo("Setup complete");
}

void loop() {
  ArduinoOTA.handle();
  logicTick();
  scheduler.execute();

  if (wifiGotIpFlag) {
    wifiGotIpFlag = false;
    if (!taskLogic.isEnabled()) {
      dispShowStatic(DISP_NOTIME);
    }
  }
}

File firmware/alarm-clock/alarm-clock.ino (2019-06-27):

/*
 * Alarm clock kit firmware for Blynk app
 * 
 * The Cave, 2019
 * https://thecave.cz
 * 
 * Licensed under MIT License (see LICENSE file for details)
 * 
 * board: LOLIN(WEMOS) D1 R2 & mini
 * 
 */
#define BLYNK_PRINT Serial
#define BLYNK_NO_FANCY_LOGO

#include <ESP8266WiFi.h>
#include <ArduinoOTA.h>
#include <Ticker.h>
#include <EEPROM.h>
#include <WiFiUdp.h>

// https://github.com/blynkkk/blynk-library
#include <BlynkSimpleEsp8266.h>
#include <WidgetRTC.h>

// https://github.com/tzapu/WiFiManager
#include <WiFiManager.h>

// https://github.com/mathertel/OneButton
#include <OneButton.h>

// https://github.com/arkhipenko/TaskScheduler
#include <TaskScheduler.h>

// https://github.com/avishorp/TM1637
#include <TM1637Display.h>

// https://github.com/PaulStoffregen/Time
#include <TimeLib.h>


#define PIN_BUZZ D5
#define PIN_CLK D6
#define PIN_DATA D7
#define PIN_BTN1 D1
#define PIN_BTN2 D2

#define BLYNK_PIN_TIMEINPUT V0
#define BLYNK_PIN_ALARMENABLE V1
#define BLYNK_PIN_COUNTDOWN_MIN V2
#define BLYNK_PIN_COUNTDOWN_SEC V3
#define BLYNK_PIN_COUNTDOWN_START V4


// Logging over Serial
#define LOG_ENABLED 1

#define RECONNECT_INTERVAL 30000UL

#define WIFI_AP_NAME "alarm-clock-"

String chipId = String(ESP.getChipId(), HEX);
Scheduler scheduler;

void placeholder() {} // keep this function here

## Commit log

2019-05-09 Add firmware, 3d prints and pcb
    [box-alarm-clock.scad, box-alarm-clock.stl, budik.brd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]
2019-05-14 Add gerber files
    [budik-panel.brd]
